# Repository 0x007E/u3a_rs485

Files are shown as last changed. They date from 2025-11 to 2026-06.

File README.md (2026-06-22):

  

# `U3A_rs485` - RS485 - Adapter for U3A



The `U3A_rs485` project is based on a ([THVD1452](#additional-information)) that ist used to change the RX/TX signals to the required differential signal level of TIA/TIA-485-A standard. It can simply be adapted to the [U3A-Module](https://github.com/0x007e/u3a).

> To use it with a [DSUB](https://www.reichelt.at/at/de/shop/produkt/d-sub_stecker_9_polig-342342) connector it is necessary to solder a connection cable to the DSUB that can be connected with the screw terminal.

| Experience | Level |
|:---|:-----:|
| Soldering | ?% |
| Mechanical  | ?% |

# Downloads

| Type | File | Description |
|:---:|:---:|:---|
| Schematic  | [pdf](https://github.com/0x007E/u3a_rs485/releases/latest/download/schematic.pdf) / [cadlab](https://cadlab.io/project/29763/main/files) | Schematic files |
| Board | [pdf](https://github.com/0x007E/u3a_rs485/releases/latest/download/pcb.pdf) / [cadlab](https://cadlab.io/project/29763/main/files) | Board file |
| Drill | [pdf](https://github.com/0x007E/u3a_rs485/releases/latest/download/drill.pdf) | Drill file |
| BoM | [xlsx](https://github.com/0x007E/u3a_rs485/releases/latest/download/bom.xlsx) / [html](https://github.com/0x007E/u3a_rs485/releases/latest/download/ibom.html) | Bill of Material as Excel/interactive HTML |
| PCB | [zip](https://github.com/0x007E/u3a_rs485/releases/latest/download/kicad.zip) / [tar](https://github.com/0x007E/u3a_rs485/releases/latest/download/kicad.tar.gz) | KiCAD/Gerber/BoM/Drill files |
| Mechanical | [zip](https://github.com/0x007E/u3a_rs485/releases/latest/download/freecad.zip) / [tar](https://github.com/0x007E/u3a_rs485/releases/latest/download/freecad.tar.gz) | FreeCAD/Housing and PCB (STEP/STL) files |

# Hardware

There are two parts of the hardware. The pcb and the housing of the `U3A_rs485`. The pcb is created with [KiCAD](#additional-information) and the housing with [FreeCAD](#additional-information). All files are built with `github actions` so that they are ready for a production environment. The housing is printed with a 3D-printer (`Dremel 3D40`).

## PCB

The circuit board is populated on both sides (Top, Bottom). The best way for soldering the `SMD` components is within a vapor phase soldering system and for the `THT` components with a standard soldering system.

### Top Layer

Top Layer

### Bottom Layer

Bottom Layer

## Mechanical

The housing has a tolerance of `0.2mm` on each side of the case. So the pcb should fit perfectly in the housing. The tolerance can be modified with `FreeCAD` in the `Parameter` Spreadsheet.

### Assembled

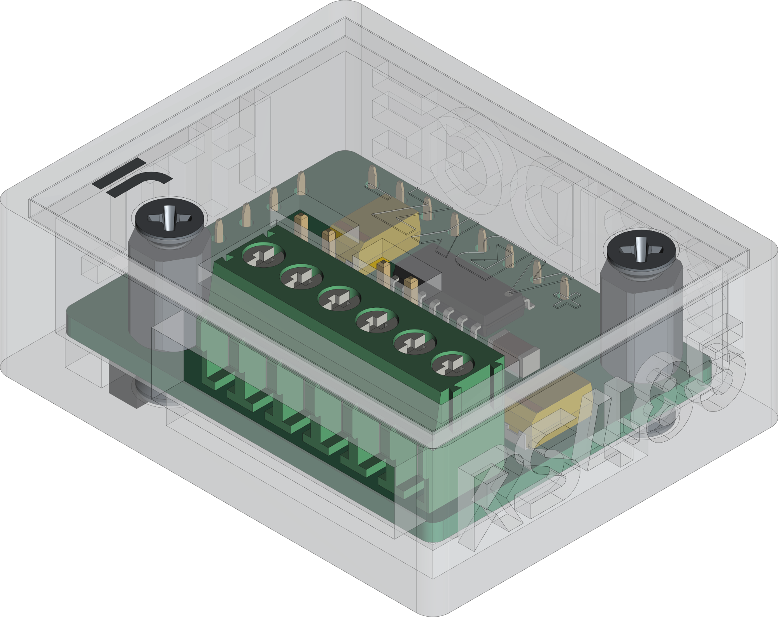
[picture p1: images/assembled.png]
Assembled


### Exploded

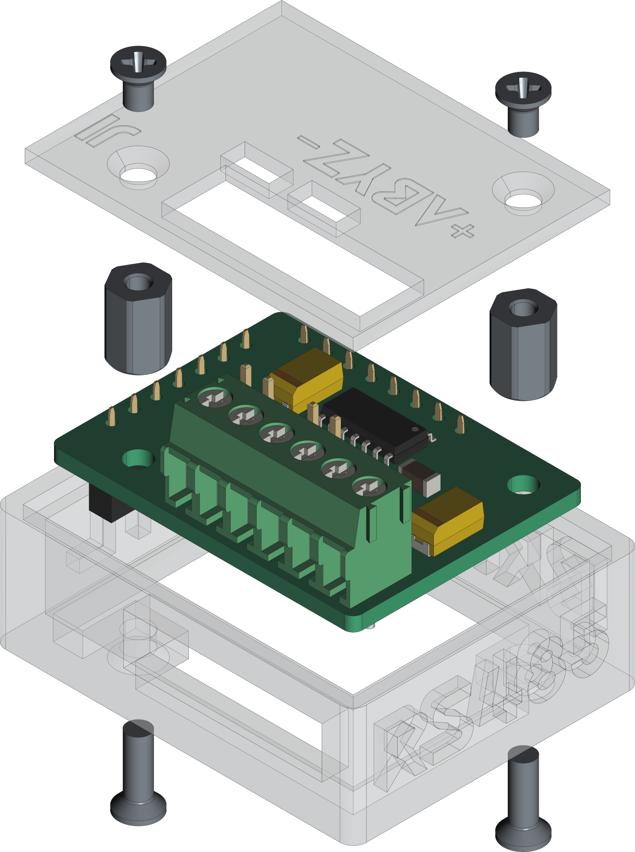
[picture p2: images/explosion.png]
Exploded


# Connection/Setup

The `U3A_rs485` is powerd over the `U3A` board with `5V`. The voltage of the pins are driven by a `THVD1452` for data transmission that meets the TIA/TIA-485-A standard.

## Simple loopback setup for testing purpose

``` bash
#
#            +-----------------------------------+           +-----------------------------------+      +---------------------+
#            |                                 J2|           |J2     U                       +---+---+  |                     |
#            | J1         U3A_rs485           +--+--+     +--+--+    S                U      |  USB  |--+ +-----------------+ |
#         +--+--+                             | VCC +-----+ VCC |    B      UPDI      3      +---+---+  | | TeraTerm        | |
#         + VCC |            T +---+          | GND +-----+ GND |    /    +---+---+   A          |      | | ~~~~~~~~        | |
#         +-----+            E | X | J        |  X  +-----| PDI |    U    |   |   |              |      | | ~~~~~           | |
#   L +---+  A  |            R | X | 3        | CTS +-----+ CTS |    A    |   |   |              |      | | ~~~~~~~~~~~~    | |
#   O | +-+  B  |            M +---+          | RTS +-----+ RTS |    R    | X | X |              |      | |                 | |
#   O +-|-+  Y  |    ~       . | X | J        | TXD +-----+ TXD |    T    +---+---+     +-+      |      | +-----------------+ |
#   P   +-+  Z  |    P   T   1 | X | 5        | RXD +-----+ RXD |    /                 / /       |      |                     |
#   B     +-----+    W   X   2 +---+          +--+--+     +--+--+    U               +-+-+-+-+-+-+      | Computer            |
#   A     + GND |    R   D   0                   |           |       P               | 5V  | 3V3 |      |                     |
#   C     +--+--+    E   E   Ω                   |           |       D               +-----+-----+      +---------------------+
#   K        |       N   N                       |           |       I         J4                |
#            | +---+---+---+---+---+---+---+---+ |           | +---+---+---+---+---+---+---+---+ |
#            | | V | C | C | D | D | D | R | G | |           | | V | C | C | D | D | D | R | G | |
#            +-+ C | B | B | C | T | C | I | N +-+           +-+ C | B | B | C | T | C | I | N +-+
#              | C | 3 | 2 | D | R | R |   | D |               | C | 3 | 2 | D | R | R |   | D |
#              +---+-+-+-+-+---+---+---+---+---+               +---+-+-+-+-+---+---+---+---+---+
#                    |   |                                           |   |
#                    |   +-------------------------------------------|---+
#                    +-----------------------------------------------+
```

# Additional Information

| Type | Link | Description |
|:---:|:---:|:---|
| THVD1452 | [pdf](https://www.ti.com/lit/ds/symlink/thvd1452.pdf) | UART / RS485 level converter |
| KiCAD | [web](https://www.kicad.org/) | KiCAD project page |
| FreeCAD | [web](https://www.freecad.org/) | FreeCAD project page |

---

R. GAECHTER

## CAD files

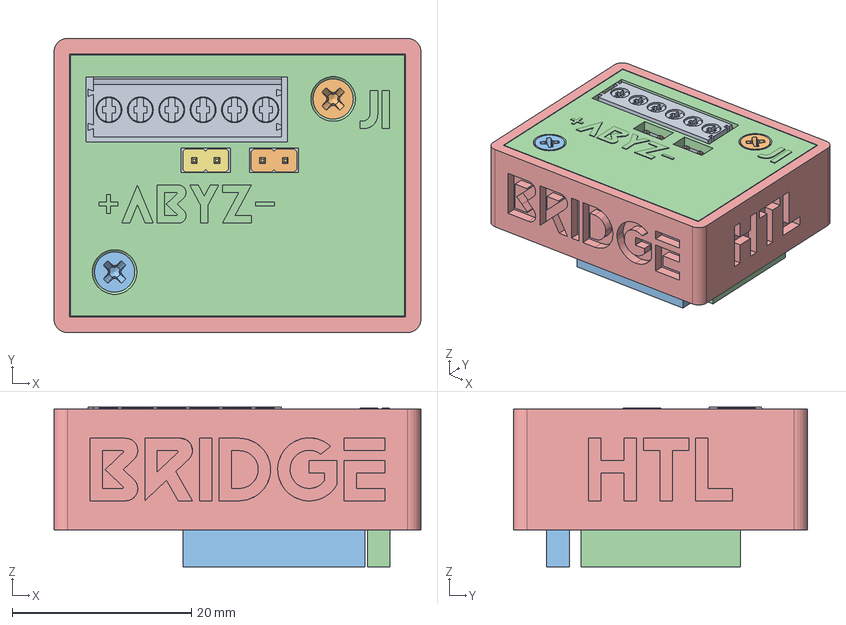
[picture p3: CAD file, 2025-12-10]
mechanical/housing.FCStd
40.9 x 32.8 x 17.8 mm
Pcb_565b
J5_PinHeader_1x02_P254mm_Vertical_247cd4d46426
C3_C_1206_3216Metric_dee17a1d5ba6
R1_R_1206_3216Metric_e4c392e16771
U1_SOIC_14_39x87mm_P127mm_7c826e366b65
C1_CP_EIA_6032_28_Kemet_C_e5fc5bf9dc3b
J3_PinHeader_1x02_P254mm_Vertical_8f4282685503
R2_R_1206_3216Metric_fd4cb68b9ab1
J1_TerminalBlock_Phoenix_PT_15_6_35_H_1x06_P350mm_Horizontal_b8abcef818d7
C2_CP_EIA_6032_28_Kemet_C_82f09277ce7b
J4_PinSocket_1x08_P254mm_Vertical_36e3868fe61d
J2_PinSocket_1x07_P254mm_Vertical_e5fd038025c4
Case
M2.5x7.5x5-Spacer
M2.5x7.5x5-Spacer001
M2.5x8-Screw
M2.5x8-Screw001
M2.5x4-Screw
M2.5x4-Screw001
Acrylglass

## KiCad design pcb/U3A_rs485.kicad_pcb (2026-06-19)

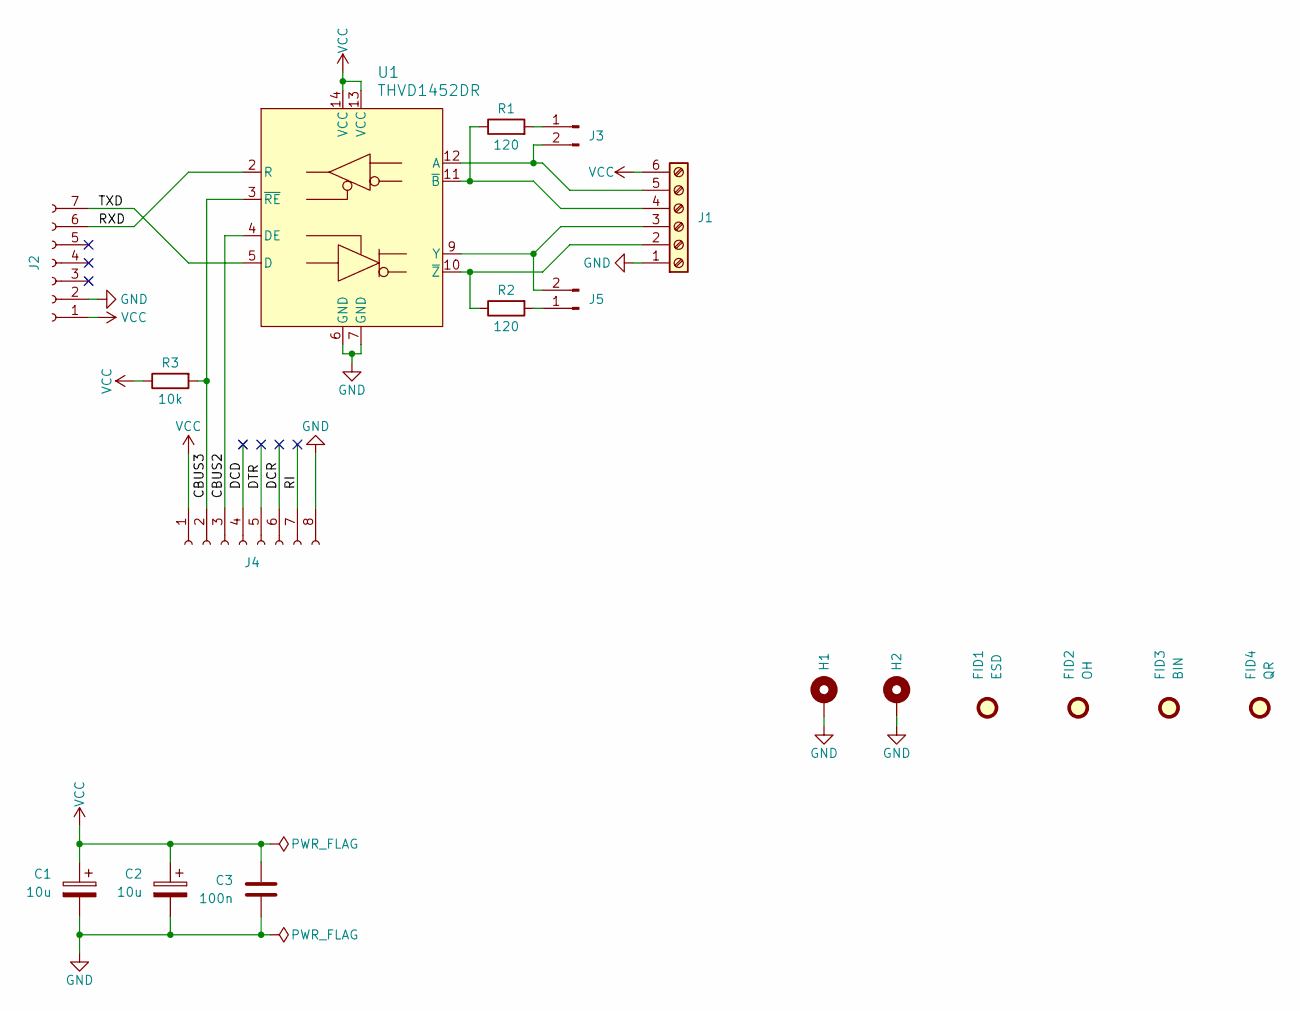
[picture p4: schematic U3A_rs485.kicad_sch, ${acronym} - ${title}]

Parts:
C1, C2: 10u; CP_EIA-6032-28_Kemet-C
C3: 100n; C_1206_3216Metric
FID1: ESD; ESD-Logo_6.6x6mm_SilkScreen
FID2: OH; OSHW-Logo_5.7x6mm_SilkScreen
FID3: BIN; WEEE-Logo_4.2x6mm_SilkScreen
FID4: QR; QR_0x007e
H1, H2: MountingHole_Pad; MountingHole_2.7mm_M2.5_Pad
J1: Screw_Terminal_01x06; TerminalBlock_Phoenix_PT-1,5-6-3.5-H_1x06_P3.50mm_Horizontal
J2: Conn_01x07_Socket; PinSocket_1x07_P2.54mm_Vertical
J3, J5: Conn_01x02_Pin; PinHeader_1x02_P2.54mm_Vertical
J4: Conn_01x08_Socket; PinSocket_1x08_P2.54mm_Vertical
R1, R2: 120; R_1206_3216Metric
R3: 10k; R_1206_3216Metric
U1: THVD1452DR; SOIC-14_3.9x8.7mm_P1.27mm

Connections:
/CBUS2: J4.3, U1.4 (DE)
/CBUS3: J4.2, R3.2, U1.3 (~RE)
/DCD: J4.4
/DCR: J4.6
/DTR: J4.5
/RI: J4.7
/RXD: J2.6, U1.2 (R)
/TXD: J2.7, U1.5 (D)
GND: C1.2, C2.2, C3.1, H1.1, H2.1, J1.1, J2.2, J4.8, U1.6 (GND), U1.7 (GND)
unnamed: J1.2, R2.1, U1.10 (~Z)
unnamed: J1.3, J5.2, U1.9 (Y)
unnamed: J1.4, R1.1, U1.11 (~B)
unnamed: J1.5, J3.2, U1.12 (A)
unnamed: J3.1, R1.2
unnamed: J5.1, R2.2
VCC: C1.1, C2.1, C3.2, J1.6, J2.1, J4.1, R3.1, U1.13 (VCC), U1.14 (VCC)

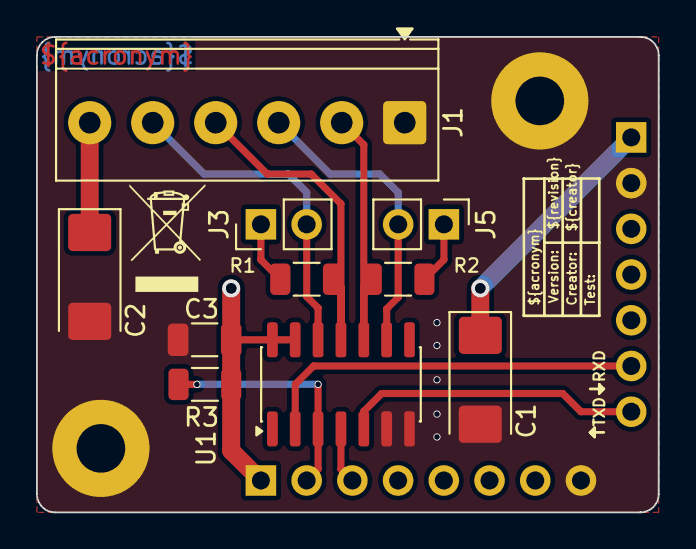
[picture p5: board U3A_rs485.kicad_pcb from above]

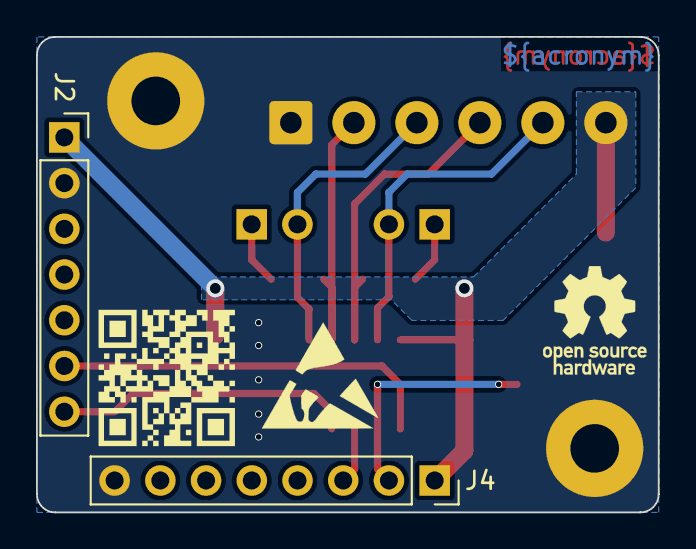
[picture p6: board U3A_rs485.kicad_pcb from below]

Board: 2 copper layers, 34.5 x 26.4 mm, 18 parts (5 on the bottom side), 12 nets.

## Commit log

2025-11-22 Add pcb layout
    [U3A_rs485.kicad_pcb, U3A_rs485.kicad_sch]
2025-11-22 Add mechanical parts
    [housing.FCStd]
2025-11-23 Add vendor-ids to devices
    [U3A_rs485.kicad_pcb, U3A_rs485.kicad_sch]
2025-11-23 Add assembly explosion
    [housing.FCStd]
2025-11-23 Add missing pull-up resistor
    [U3A_rs485.kicad_pcb, U3A_rs485.kicad_sch]
2025-11-24 Update THVD1452 symbol color
    [U3A_rs485.kicad_sch]
2025-11-26 Change vendor of parts
    [U3A_rs485.kicad_pcb, U3A_rs485.kicad_sch]
2025-12-10 Move pcb to part
    [housing.FCStd]
2026-06-19 Update to KiCAD 9
    [U3A_rs485.kicad_pcb, U3A_rs485.kicad_sch]
2026-06-19 Rename/Add/Remove bom fields
    [U3A_rs485.kicad_pcb, U3A_rs485.kicad_sch]
2026-06-22 Add missing values in bom

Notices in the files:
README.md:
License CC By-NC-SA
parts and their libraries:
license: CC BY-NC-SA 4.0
